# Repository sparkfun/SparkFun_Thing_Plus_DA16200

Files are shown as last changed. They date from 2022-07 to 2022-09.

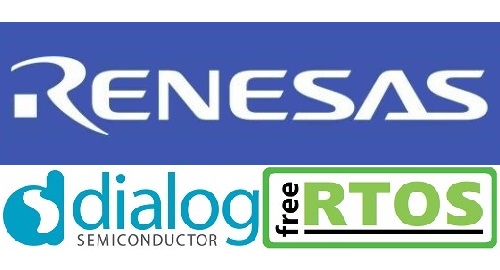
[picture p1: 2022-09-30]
docs/img/sdk_guide/thumbnail/thumbnail.jpg

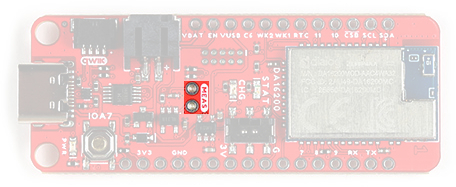
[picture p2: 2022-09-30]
docs/img/hookup_guide/DA16200_thing_plus-MEAS.jpg

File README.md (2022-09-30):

SparkFun Thing Plus - DA16200
========================================

SparkFun Thing Plus - DA16200 (https://www.sparkfun.com/products/19696)

[*SparkFun Thing Plus - DA16200 (WRL-19696)*](https://www.sparkfun.com/products/19696)

The DA16200MOD is an ultra low power WiFi module manufactured by [Dialog (a subsidiary of Renesas)](https://www.renesas.com/us/en). It contains a 802.11b/g/n radio (PHY), a baseband processor, a media access controller (MAC), on-chip memory, and a host networking application processor, all on a single silicon die. The system on a chip (SoC) has full offload capabilities to run the entire networking OS and TCP/IP stack on chip; therefore, an external network processor, CPU, or microcontroller are not required.

The module is Wi-Fi Alliance certified for IEEE802.11b/g/n, Wi-Fi Direct, WPS functionalities and it has been approved by many countries including the United States (FCC), Canada (IC) and China (SRRC). Using the Wi-Fi Alliance transfer policy, the Wi-Fi Certifications can be transferred without being tested again. 

This module is now available in a [Thing Plus form factor](https://www.sparkfun.com/thing_plus), which includes a Qwiic and LiPo battery connectors, multiple GPIO pins, and JTAG PTH pins for debugging. The SparkFun Thing Plus - DA16200 is ideal for your next IoT project, thanks in part to the multiple sleep modes that allow you to take advantage of current draws as low as 0.2 - 3.5 &micro;A on the WiFi module.

***Note:** Please be aware that the Thing Plus - DA16200 has a **3.3V** logic level voltage.*

_The SparkFun [Qwiic connect system](https://www.sparkfun.com/qwiic) is an ecosystem of I2C sensors, actuators, shields and cables that make prototyping faster and less prone to error. All Qwiic-enabled boards use a common 1mm pitch, 4-pin JST connector. This reduces the amount of required PCB space, and polarized connections mean you can't hook it up wrong._

Repository Contents
-------------------

* **[/docs](/docs/)** - Documentation files
    * [board_files](/docs/board_files/) - Files for the product design
        * [Eagle design files](/docs/board_files/eagle_files.zip) (.zip)
        * [Schematic](/docs/board_files/schematic.pdf) (.pdf)
        * [Dimensions](/docs/board_files/dimensions.pdf) (.pdf)
    * [component_documentation](/docs/component_datasheets/) - Datasheets and guides for hardware components
    * [img/hookup_guide/](/docs/img/hookup_guide/) - Images for hookup guide documentation
* **[/Firmware](/Firmware/)** - Prebuilt Example Projects
* **/Hardware** - Eagle design files (.brd, .sch)
* **/Hardware/Production** - Production panel files (.brd)
* **Logic Analyzer Data** - Logic analyzer data from testing

Documentation
--------------

* [DA16200MOD Datasheet](https://www.renesas.com/document/dst/da16200mod-datasheet?language=en&r=1599971) (v3.1)
* [Hookup Guide](https://learn.sparkfun.com/tutorials/2517)
* [Getting Started with the DA16200 FreeRTOS SDK Tutorial](https://learn.sparkfun.com/tutorials/2418)
* [Dialog DA16200MOD Product Page](https://www.renesas.com/us/en/products/interface-connectivity/wireless-communications/wi-fi/da16200mod-ultra-low-power-wi-fi-modules-battery-powered-iot-devices)
  * [Documentation for the DA16200](https://www.renesas.com/us/en/products/interface-connectivity/wireless-communications/wi-fi/da16200mod-ultra-low-power-wi-fi-modules-battery-powered-iot-devices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)       
  * [Software and Tools for the DA16200](https://www.renesas.com/us/en/products/interface-connectivity/wireless-communications/wi-fi/da16200mod-ultra-low-power-wi-fi-modules-battery-powered-iot-devices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)
  * [Support for the DA16200](https://www.renesas.com/us/en/products/interface-connectivity/wireless-communications/wi-fi/da16200mod-ultra-low-power-wi-fi-modules-battery-powered-iot-devices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)
    * [RenesasRulz Forum](https://renesasrulz.com/)

Product Versions
----------------
* [WRL-19696](https://www.sparkfun.com/products/19696) -  initial release

License Information
-------------------

This product is _**open source**_! 

Please review the LICENSE.md file for license information. 

If you have any questions or concerns on licensing, please contact technical support on our [SparkFun forums](https://forum.sparkfun.com/index.php).

Distributed as-is; no warranty is given.

- Your friends at SparkFun.

_<COLLABORATION CREDIT>_

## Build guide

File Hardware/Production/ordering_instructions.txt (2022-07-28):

panel size, 107x204mm
PCB thickness, 1.6mm
number of layers, 4
soldermask color, Red
silkscreen color, White
oz copper, 1oz
finish, HASL lead free
stencils, top
pcs per panel, 12
min trace width, 0.1778mm / 0.0070in
min drill size, 0.3048mm / 0.0120in
filename to layer stackup 1/2/3/4: GTL, GL2, GL3, GBL

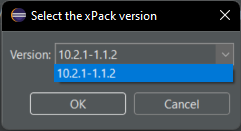
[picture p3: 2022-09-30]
docs/img/sdk_guide/eclipse-preferences-arm_toolchain-xpack_version.png

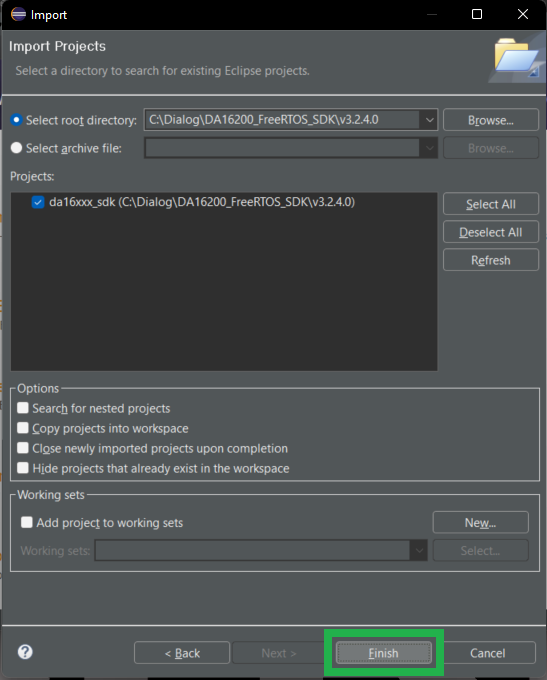
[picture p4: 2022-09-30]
docs/img/sdk_guide/eclipse-import_projects-finish.png

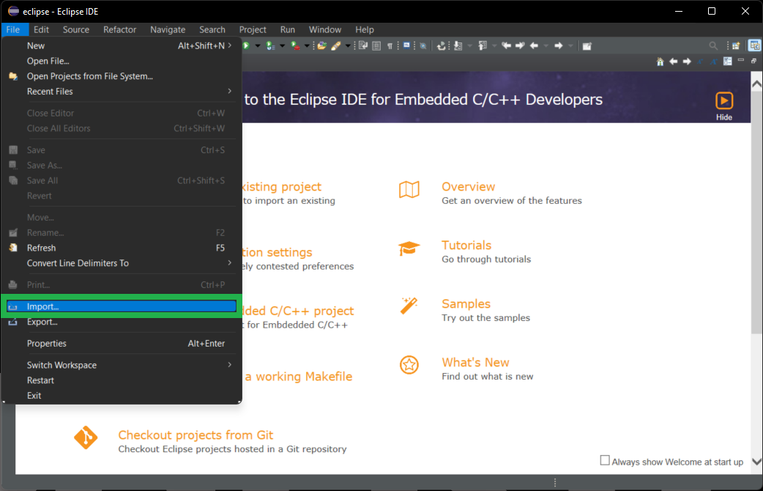
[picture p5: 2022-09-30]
docs/img/sdk_guide/eclipse-file_menu-import.png

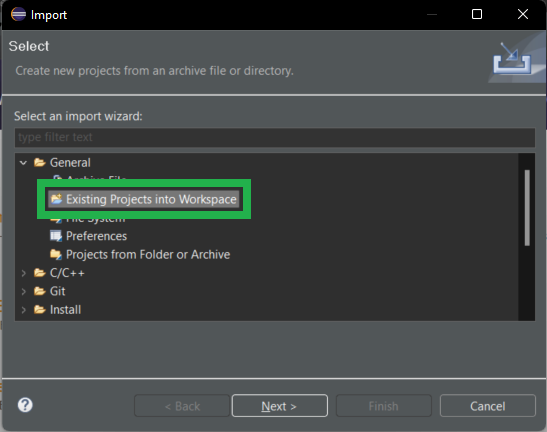
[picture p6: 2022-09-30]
docs/img/sdk_guide/eclipse-import_select.png

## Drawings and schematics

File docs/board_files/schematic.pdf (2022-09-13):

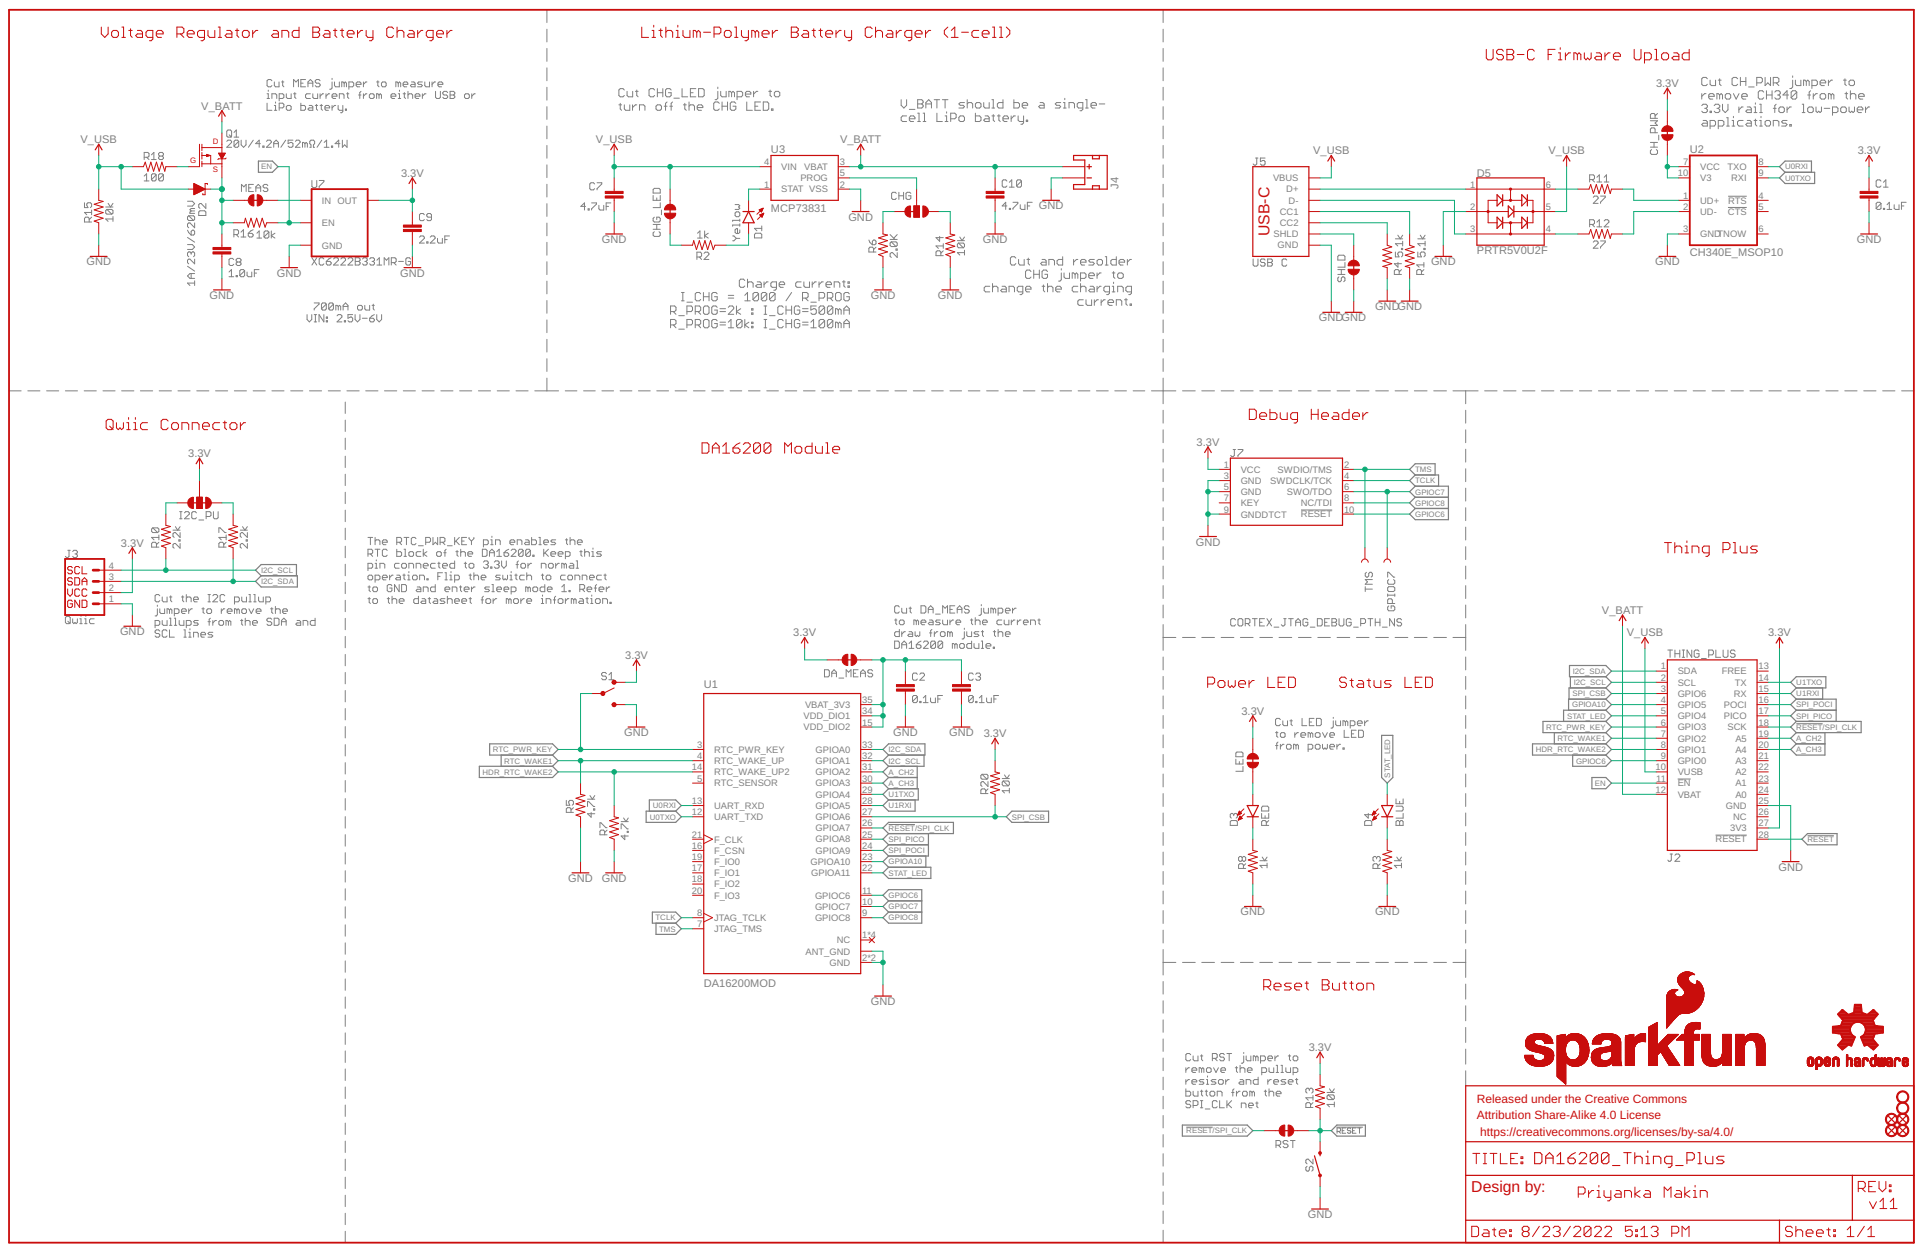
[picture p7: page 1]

Released under the Creative Commons Attribution Share-Alike 4.0 License

https://creativecommons.org/licenses/by-sa/4.0/ Design by:

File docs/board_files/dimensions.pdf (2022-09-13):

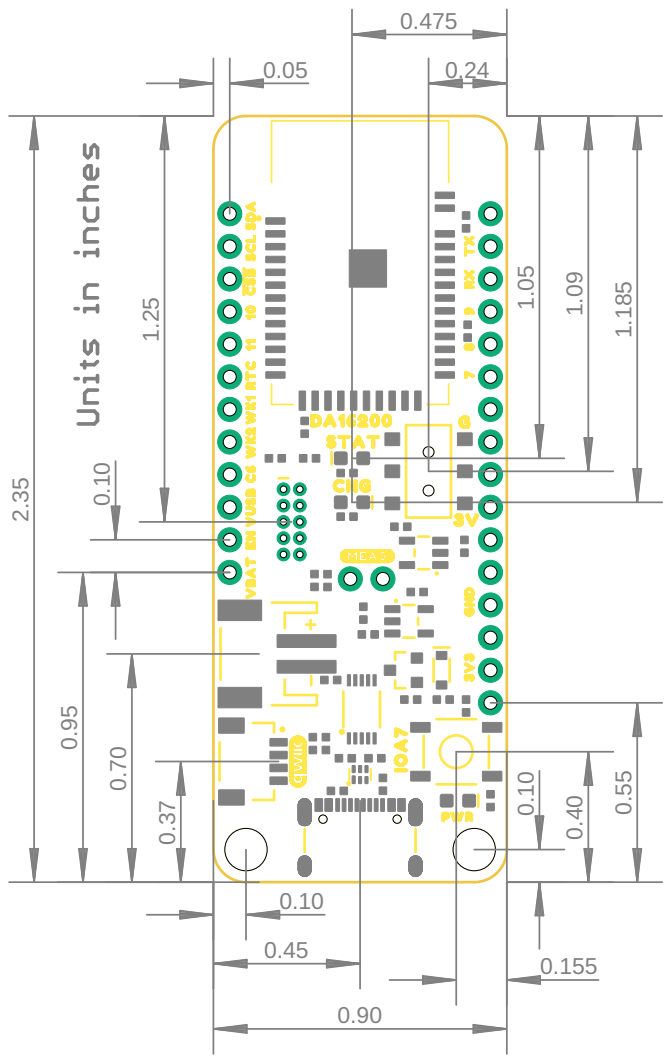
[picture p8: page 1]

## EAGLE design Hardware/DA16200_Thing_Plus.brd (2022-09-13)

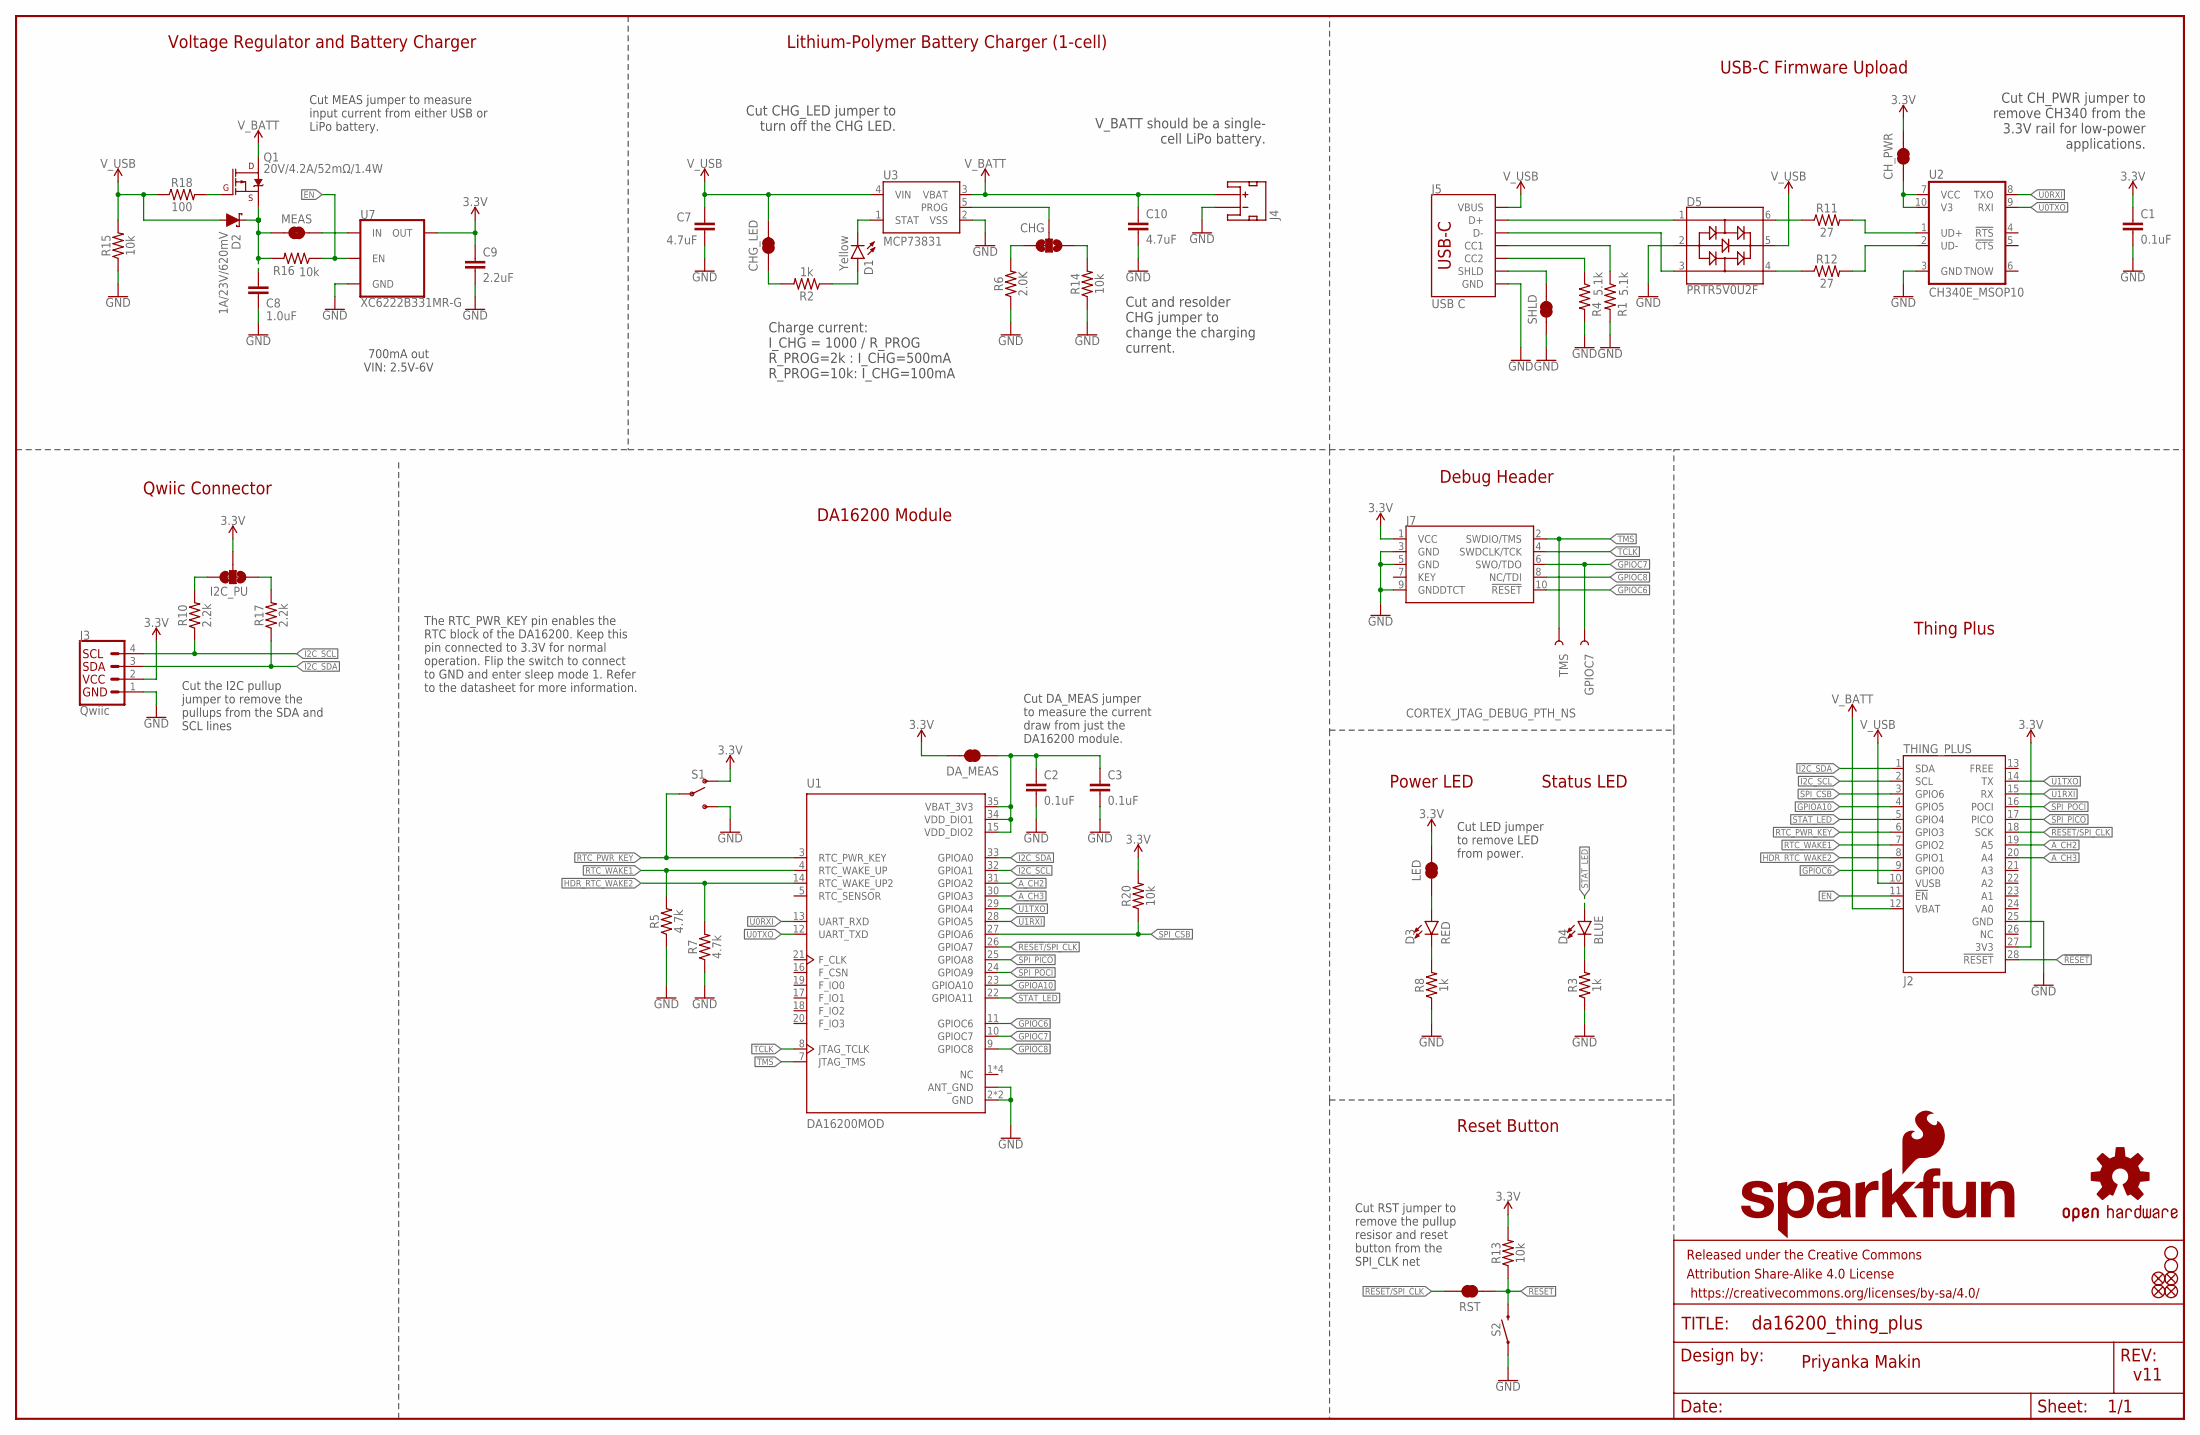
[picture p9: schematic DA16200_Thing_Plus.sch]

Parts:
C1, C2, C3: 0.1uF; 0402-TIGHT
C7, C10: 4.7uF; 0402-TIGHT
C8: 1.0uF; 0402-TIGHT
C9: 2.2uF; 0402-TIGHT
CHG: JUMPER-SMT_3_1-NC_TRACE_SILK; SMT-JUMPER_3_1-NC_TRACE_SILK
CHG_LED: JUMPER-SMT_2_NC_TRACE_SILK; SMT-JUMPER_2_NC_TRACE_SILK
CH_PWR: JUMPER-SMT_2_NC_TRACE_SILK; SMT-JUMPER_2_NC_TRACE_SILK
D1: Yellow; LED-0603
D2: 1A/23V/620mV; SOD-323
D3: RED; LED-0603
D4: BLUE; LED-0603
D5: PRTR5V0U2F; SOT886
DA_MEAS: JUMPER-SMT_2_NC_TRACE_SILK; SMT-JUMPER_2_NC_TRACE_SILK
FD1, FD2, FD3, FD4: FIDUCIALUFIDUCIAL; FIDUCIAL-MICRO
FRAME1: FRAME-LEDGER; CREATIVE_COMMONS
GPIOC7: TEST-POINT3; PAD.03X.03
H3, H4: STAND-OFF
I2C_PU: JUMPER-SMT_3_2-NC_TRACE_SILK; SMT-JUMPER_3_2-NC_TRACE_SILK
J2: THING_PLUS
J3: Qwiic; JST04_1MM_RA
J4: JST_2MM_MALE; JST-2-SMD
J5: USB C; USB-C-16P-4LAYER-ISOLATED
J7: CORTEX_JTAG_DEBUG_PTH_NS; 2X5-PTH-1.27MM-NO_SILK
LED: JUMPER-SMT_2_NC_TRACE_SILK; SMT-JUMPER_2_NC_TRACE_SILK
LOGO1: OSHW-LOGOS; OSHW-LOGO-S
LOGO2: SFE_LOGO_NAME_FLAME.1_INCH; SFE_LOGO_NAME_FLAME_.1
MEAS: JUMPER-COMBO_2_NC_TRACE; COMBO-JUMPER_2_NC_TRACE
Q1: 20V/4.2A/52mΩ/1.4W; SOT23-3
R1, R4: 5.1k; 0402-TIGHT
R2, R3, R8: 1k; 0402-TIGHT
R5, R7: 4.7k; 0402-TIGHT
R6: 2.0K; 0402-TIGHT
R10, R17: 2.2k; 0402-TIGHT
R11, R12: 27; 0402-TIGHT
R13, R14, R15, R16, R20: 10k; 0402-TIGHT
R18: 100; 0402-TIGHT
RST: JUMPER-SMT_2_NC_TRACE_SILK; SMT-JUMPER_2_NC_TRACE_SILK
S1: SWITCH-SPDT-SMD-AYZ0202; SWITCH_DPDT_SMD_AYZ0202
S2: MOMENTARY-SWITCH-SPST-SMD-5.2MM-TALL; TACTILE_SWITCH_SMD_5.2MM
SHLD: JUMPER-SMT_2_NC_TRACE_SILK; SMT-JUMPER_2_NC_TRACE_SILK
TMS: TEST-POINT3; PAD.03X.03
U1: DA16200MOD; XCVR_DA16200MOD-AAC4WA32
U2: CH340E_MSOP10; MSOP10
U3: MCP73831; SOT23-5
U7: XC6222B331MR-G; SOT23-5

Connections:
3.3V: C1.1, C9.1, CH_PWR.2, DA_MEAS.2, I2C_PU.2, J2.27 (3V3), J3.2, J7.1 (VCC), LED.2, R13.2, R20.2, S1.1 (O), U7.5 (OUT)
!RESET!: J2.28 (!RESET), R13.1, RST.1, S2.3 (2)
!RESET!/SPI_CLK: J2.18 (SCK), RST.2, U1.26 (GPIOA7)
A_CH2: J2.19 (A5), U1.31 (GPIOA2)
A_CH3: J2.20 (A4), U1.30 (GPIOA3)
EN: J2.11 (!EN), R16.1, U7.3 (EN)
GND: C1.2, C2.2, C3.2, C7.2, C8.2, C9.2, C10.2, D5.2, J2.25 (GND), J3.1, J4.1 (-), J5.GND, J5.GND2 (GND), J7.3 (GND), J7.5 (GND), J7.9 (GNDDTCT), R1.2, R3.1, R4.2, R5.1, R6.1, R7.1, R8.1, R14.1, R15.1, S1.3 (S), S2.1, SHLD.1, U1.2 (GND), U1.ANT_GND, U1.GND, U2.3 (GND), U3.2 (VSS), U7.2 (GND)
GPIOA10: J2.4 (GPIO5), U1.23 (GPIOA10)
GPIOC6: J2.9 (GPIO0), J7.10 (!RESET), U1.11 (GPIOC6)
GPIOC7: GPIOC7.1, J7.6 (SWO/TDO), U1.10 (GPIOC7)
GPIOC8: J7.8 (NC/TDI), U1.9 (GPIOC8)
HDR_RTC_WAKE2: J2.8 (GPIO1), R7.2, U1.14 (RTC_WAKE_UP2)
I2C_SCL: J2.2 (SCL), J3.4, R10.1, U1.32 (GPIOA1)
I2C_SDA: J2.1 (SDA), J3.3, R17.1, U1.33 (GPIOA0)
unnamed: D4.C, R3.2
unnamed: I2C_PU.3, R10.2
unnamed: I2C_PU.1, R17.2
unnamed: D3.A, LED.1
unnamed: D5.1, J5.A6 (D+), J5.B6 (D+)
unnamed: D5.3, J5.A7 (D-), J5.B7 (D-)
unnamed: D3.C, R8.2
unnamed: C2.1, C3.1, DA_MEAS.1, U1.15 (VDD_DIO2), U1.34 (VDD_DIO1), U1.35 (VBAT_3V3)
unnamed: D1.C, U3.1 (STAT)
unnamed: CHG.3, R6.2
unnamed: J5.A5 (CC1), R1.1
unnamed: J5.B5 (CC2), R4.1
unnamed: D5.6, R11.1
unnamed: CHG.2, U3.5 (PROG)
unnamed: C8.1, D2.C, MEAS.1, MEAS.3 (1), Q1.2 (S), R16.2
unnamed: D5.4, R12.1
unnamed: D1.A, R2.1
unnamed: R11.2, U2.1 (UD+)
unnamed: R12.2, U2.2 (UD-)
unnamed: CHG.1, R14.2
unnamed: Q1.1 (G), R18.2
unnamed: MEAS.2, MEAS.4 (2), U7.1 (IN)
unnamed: CHG_LED.1, R2.2
unnamed: J5.SHLD1 (SHLD), J5.SHLD2 (SHLD), J5.SHLD3 (SHLD), J5.SHLD4 (SHLD), J5.SHLD5 (SHLD), J5.SHLD6 (SHLD), J5.SHLD7 (SHLD), J5.SHLD8 (SHLD), SHLD.2
unnamed: CH_PWR.1, U2.7 (VCC), U2.10 (V3)
RTC_PWR_KEY: J2.6 (GPIO3), S1.2, U1.3 (RTC_PWR_KEY)
RTC_WAKE1: J2.7 (GPIO2), R5.2, U1.4 (RTC_WAKE_UP)
SPI_CSB: J2.3 (GPIO6), R20.1, U1.27 (GPIOA6)
SPI_PICO: J2.17 (PICO), U1.25 (GPIOA8)
SPI_POCI: J2.16 (POCI), U1.24 (GPIOA9)
STAT_LED: D4.A, J2.5 (GPIO4), U1.22 (GPIOA11)
TCLK: J7.4 (SWDCLK/TCK), U1.8 (JTAG_TCLK)
TMS: J7.2 (SWDIO/TMS), TMS.1, U1.7 (JTAG_TMS)
U0RXI: U1.13 (UART_RXD), U2.8 (TXO)
U0TXO: U1.12 (UART_TXD), U2.9 (RXI)
U1RXI: J2.15 (RX), U1.28 (GPIOA5)
U1TXO: J2.14 (TX), U1.29 (GPIOA4)
V_BATT: C10.1, J2.12 (VBAT), J4.2 (+), Q1.3 (D), U3.3 (VBAT)
V_USB: C7.1, CHG_LED.2, D2.A, D5.5, J2.10 (VUSB), J5.VBUS1 (VBUS), J5.VBUS2 (VBUS), R15.2, R18.1, U3.4 (VIN)

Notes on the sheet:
V_BATT should be a single- cell LiPo battery.
Charge current: I_CHG = 1000 / R_PROG R_PROG=2k : I_CHG=500mA R_PROG=10k: I_CHG=100mA
Voltage Regulator and Battery Charger
Lithium-Polymer Battery Charger (1-cell)
700mA out VIN: 2.5V-6V
Reset Button
Status LED
Thing Plus
v11
Qwiic Connector
USB-C Firmware Upload
Cut the I2C pullup jumper to remove the pullups from the SDA and SCL lines
Debug Header
Power LED
Priyanka Makin
DA16200 Module
Cut MEAS jumper to measure input current from either USB or LiPo battery.
Cut and resolder CHG jumper to change the charging current.
Cut LED jumper to remove LED from power.
The RTC_PWR_KEY pin enables the RTC block of the DA16200. Keep this pin connected to 3.3V for normal operation. Flip the switch to connect to GND and enter sleep mode 1. Refer to the datasheet for more information.
Cut DA_MEAS jumper to measure the current draw from just the DA16200 module.
Cut CHG_LED jumper to turn off the CHG LED.
Cut CH_PWR jumper to remove CH340 from the 3.3V rail for low-power applications.
Cut RST jumper to remove the pullup resisor and reset button from the SPI_CLK net

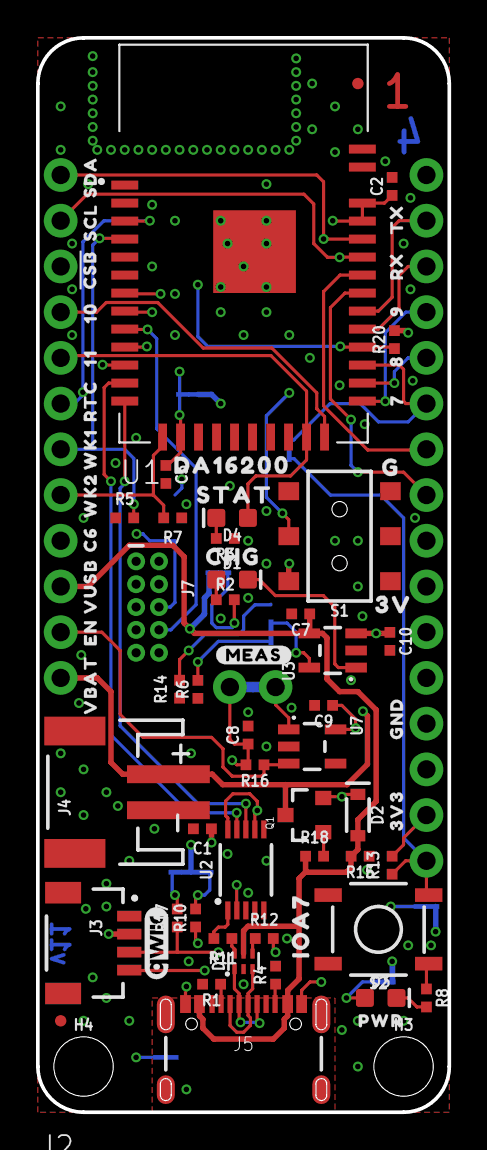
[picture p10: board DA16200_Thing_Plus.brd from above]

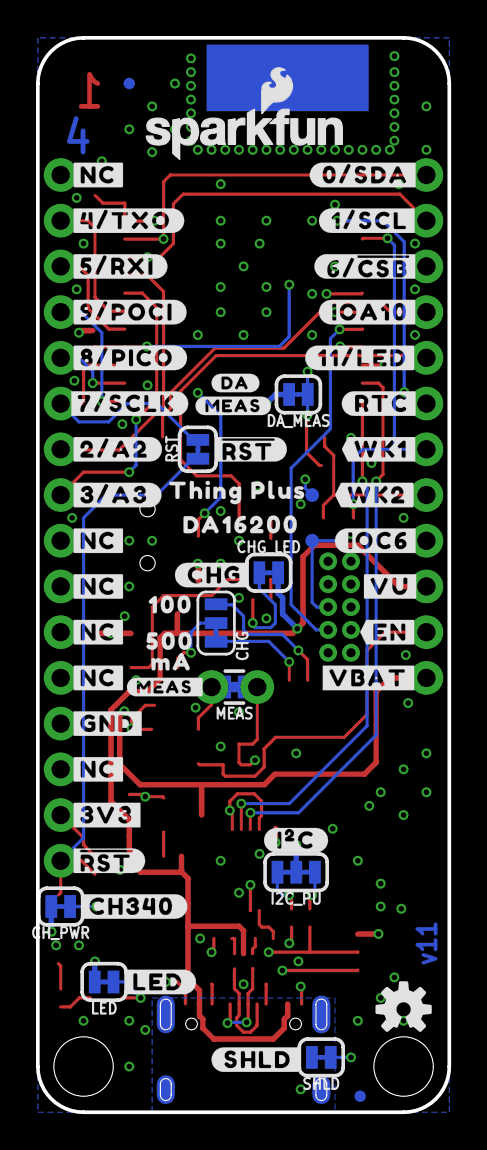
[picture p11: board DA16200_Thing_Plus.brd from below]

Board: 4 copper layers, 22.9 x 59.7 mm, 133 parts (57 on the bottom side), 53 nets.

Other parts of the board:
U$1: STAT0
U$2: CHG0
U$3: #MEAS_#0
U$4: G0
U$5, U$43: ##RST##0
U$6: #VU#0
U$7: #IOA10#0
U$8, U$29: #MEAS#0
U$9: 3V0
U$10: #CH340#0
U$11: #0#SDA#0
U$12: #1#SCL#0
U$13: IOA7_0
U$14, U$15, U$18, U$19, U$20, U$40: #NC#0
U$16: PWR0
U$17: #DA#0
U$21: 5000
U$22: 1000
U$23: MA0
U$24: SDA0
U$25: SCL0
U$26: #CSB#0
U$27: #4#TXO#0
U$28: 110
U$30: #VBAT#0
U$31: ORDERING_INSTRUCTIONS
U$32: 100
U$33: RTC0
U$34: WK10
U$35: WK20
U$36: #5#RXI#0
U$37: EN0
U$38: VUSB0
U$39: VBAT0
U$41: TX0
U$42: RX0
U$44: 90
U$45: 80
U$47: 70
U$50: #GND#0
U$51: #3V3#0
U$53: #EN#0
U$55: GND0
U$56: THING_PLUS0
U$57: 3V30
U$59: #CHG#0
U$60: #IOC6#0
U$62: #6##CSB##0
U$63: #11#LED#0
U$64: QWIIC_4MM
U$65: C60
U$66: #9#POCI#0
U$67: #8#PICO#0
U$68: #7#SCLK#0
U$69: #2#A2#0
U$70: #3#A3#0
U$71: #WK2#0
U$72: #WK1#0
U$73: #RTC#0
U$80, U$81: DA162000
U$82: #I�C#0
U$84: #LED#0
U$85: #SHLD#0

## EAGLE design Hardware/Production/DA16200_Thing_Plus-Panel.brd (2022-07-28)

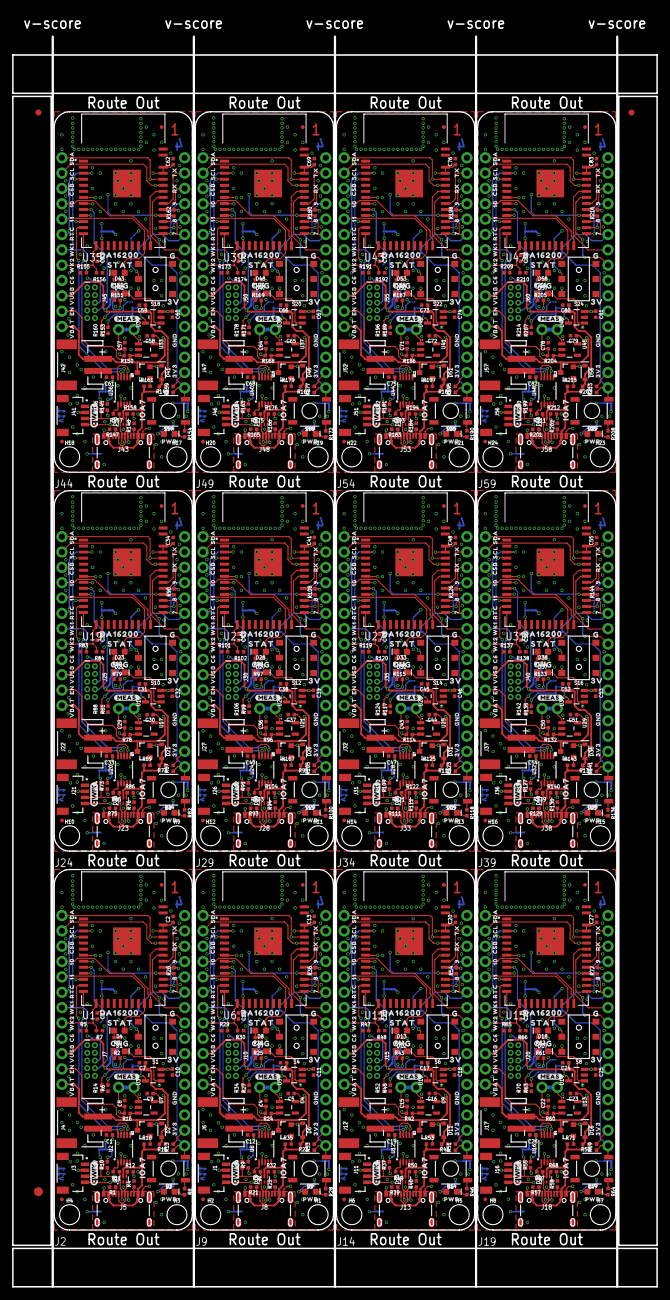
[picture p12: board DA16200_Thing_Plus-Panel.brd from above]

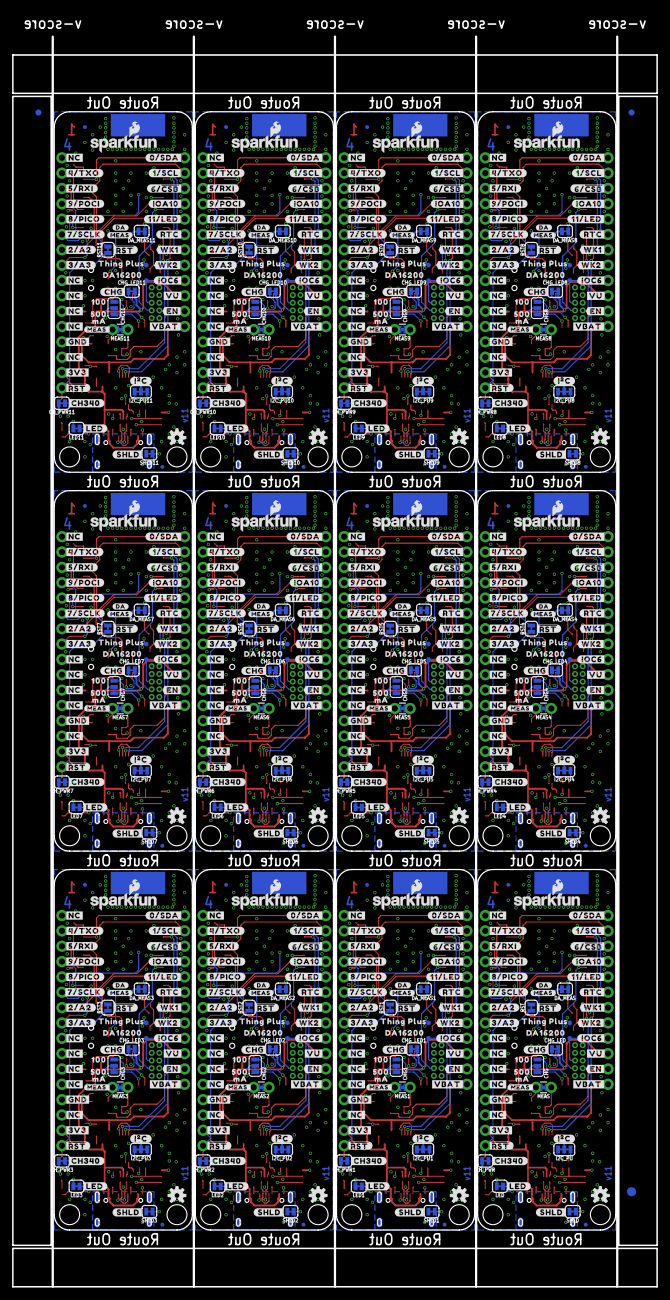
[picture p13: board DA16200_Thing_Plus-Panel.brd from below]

Board: 4 copper layers, 106.7 x 207.0 mm, 1578 parts (687 on the bottom side), 636 nets.

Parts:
C1, C2, C3, C12, C13, C14, C19, C20, C21, C26, C27, C28, C33, C34, C35, C40, C41, C42, C47, C48, C49, C54, C55, C56, C61, C62, C63, C68, C69, C70, C75, C76, C77, C82, C83, C84: 0.1uF; 0402-TIGHT
C4, C8, C15, C22, C29, C36, C43, C50, C57, C64, C71, C78: 1.0uF; 0402-TIGHT
C5, C9, C16, C23, C30, C37, C44, C51, C58, C65, C72, C79: 2.2uF; 0402-TIGHT
C6, C7, C10, C11, C17, C18, C24, C25, C31, C32, C38, C39, C45, C46, C52, C53, C59, C60, C66, C67, C73, C74, C80, C81: 4.7uF; 0402-TIGHT
CHG, CHG1, CHG2, CHG3, CHG4, CHG5, CHG6, CHG7, CHG8, CHG9, CHG10, CHG11: JUMPER-SMT_3_1-NC_TRACE_SILK; SMT-JUMPER_3_1-NC_TRACE_SILK
CHG_LED, CHG_LED1, CHG_LED2, CHG_LED3, CHG_LED4, CHG_LED5, CHG_LED6, CHG_LED7, CHG_LED8, CHG_LED9, CHG_LED10, CHG_LED11: JUMPER-SMT_2_NC_TRACE_SILK; SMT-JUMPER_2_NC_TRACE_SILK
CH_PWR, CH_PWR1, CH_PWR2, CH_PWR3, CH_PWR4, CH_PWR5, CH_PWR6, CH_PWR7, CH_PWR8, CH_PWR9, CH_PWR10, CH_PWR11: JUMPER-SMT_2_NC_TRACE_SILK; SMT-JUMPER_2_NC_TRACE_SILK
D1, D7, D12, D17, D22, D27, D32, D37, D42, D47, D52, D57: Yellow; LED-0603
D2, D6, D11, D16, D21, D26, D31, D36, D41, D46, D51, D56: 1A/23V/620mV; SOD-323
D3, D9, D14, D19, D24, D29, D34, D39, D44, D49, D54, D59: RED; LED-0603
D4, D8, D13, D18, D23, D28, D33, D38, D43, D48, D53, D58: BLUE; LED-0603
D5, D10, D15, D20, D25, D30, D35, D40, D45, D50, D55, D60: PRTR5V0U2F; SOT886
DA_MEAS, DA_MEAS1, DA_MEAS2, DA_MEAS3, DA_MEAS4, DA_MEAS5, DA_MEAS6, DA_MEAS7, DA_MEAS8, DA_MEAS9, DA_MEAS10, DA_MEAS11: JUMPER-SMT_2_NC_TRACE_SILK; SMT-JUMPER_2_NC_TRACE_SILK
E$1, E$2, E$3, E$4: FIDUCIAL-1X2
E$5, E$6: FIDUCIAL-1.5X3
FD1, FD2, FD3, FD4, FD5, FD6, FD7, FD8, FD9, FD10, FD11, FD12, FD13, FD14, FD15, FD16, FD17, FD18, FD19, FD20, FD21, FD22, FD23, FD24, FD25, FD26, FD27, FD28, FD29, FD30, FD31, FD32, FD33, FD34, FD35, FD36, FD37, FD38, FD39, FD40, FD41, FD42, FD43, FD44, FD45, FD46, FD47, FD48: FIDUCIALUFIDUCIAL; FIDUCIAL-MICRO
GPIOC1, GPIOC2, GPIOC3, GPIOC4, GPIOC5, GPIOC6, GPIOC7, GPIOC8, GPIOC9, GPIOC10, GPIOC11, GPIOC12: TEST-POINT3; PAD.03X.03
H1, H2, H3, H4, H5, H6, H7, H8, H9, H10, H11, H12, H13, H14, H15, H16, H17, H18, H19, H20, H21, H22, H23, H24: STAND-OFF
I2C_PU, I2C_PU1, I2C_PU2, I2C_PU3, I2C_PU4, I2C_PU5, I2C_PU6, I2C_PU7, I2C_PU8, I2C_PU9, I2C_PU10, I2C_PU11: JUMPER-SMT_3_2-NC_TRACE_SILK; SMT-JUMPER_3_2-NC_TRACE_SILK
J1, J3, J11, J16, J21, J26, J31, J36, J41, J46, J51, J56: Qwiic; JST04_1MM_RA
J2, J9, J14, J19, J24, J29, J34, J39, J44, J49, J54, J59: THING_PLUS
J4, J6, J12, J17, J22, J27, J32, J37, J42, J47, J52, J57: JST-2-SMD
J5, J8, J13, J18, J23, J28, J33, J38, J43, J48, J53, J58: USB C; USB-C-16P-4LAYER-ISOLATED
J7, J10, J15, J20, J25, J30, J35, J40, J45, J50, J55, J60: CORTEX_JTAG_DEBUG_PTH_NS; 2X5-PTH-1.27MM-NO_SILK
LED, LED1, LED2, LED3, LED4, LED5, LED6, LED7, LED8, LED9, LED10, LED11: JUMPER-SMT_2_NC_TRACE_SILK; SMT-JUMPER_2_NC_TRACE_SILK
LOGO1, LOGO3, LOGO5, LOGO7, LOGO9, LOGO11, LOGO13, LOGO15, LOGO17, LOGO19, LOGO21, LOGO23: OSHW-LOGOS; OSHW-LOGO-S
LOGO2, LOGO4, LOGO6, LOGO8, LOGO10, LOGO12, LOGO14, LOGO16, LOGO18, LOGO20, LOGO22, LOGO24: SFE_LOGO_NAME_FLAME.1_INCH; SFE_LOGO_NAME_FLAME_.1
MEAS, MEAS1, MEAS2, MEAS3, MEAS4, MEAS5, MEAS6, MEAS7, MEAS8, MEAS9, MEAS10, MEAS11: JUMPER-COMBO_2_NC_TRACE; COMBO-JUMPER_2_NC_TRACE
Q1, Q2, Q3, Q4, Q5, Q6, Q7, Q8, Q9, Q10, Q11, Q12: 20V/4.2A/52mΩ/1.4W; SOT23-3
R1, R4, R21, R22, R39, R40, R57, R58, R75, R76, R93, R94, R111, R112, R129, R130, R147, R148, R165, R166, R183, R184, R201, R202: 5.1k; 0402-TIGHT
R2, R3, R8, R25, R26, R28, R43, R44, R46, R61, R62, R64, R79, R80, R82, R97, R98, R100, R115, R116, R118, R133, R134, R136, R151, R152, R154, R169, R170, R172, R187, R188, R190, R205, R206, R208: 1k; 0402-TIGHT
R5, R7, R29, R30, R47, R48, R65, R66, R83, R84, R101, R102, R119, R120, R137, R138, R155, R156, R173, R174, R191, R192, R209, R210: 4.7k; 0402-TIGHT
R6, R27, R45, R63, R81, R99, R117, R135, R153, R171, R189, R207: 2.0K; 0402-TIGHT
R9, R10, R17, R19, R37, R38, R55, R56, R73, R74, R91, R92, R109, R110, R127, R128, R145, R146, R163, R164, R181, R182, R199, R200: 2.2k; 0402-TIGHT
R11, R12, R31, R32, R49, R50, R67, R68, R85, R86, R103, R104, R121, R122, R139, R140, R157, R158, R175, R176, R193, R194, R211, R212: 27; 0402-TIGHT
R13, R14, R15, R16, R20, R23, R24, R33, R34, R36, R41, R42, R51, R52, R54, R59, R60, R69, R70, R72, R77, R78, R87, R88, R90, R95, R96, R105, R106, R108, R113, R114, R123, R124, R126, R131, R132, R141, R142, R144, R149, R150, R159, R160, R162, R167, R168, R177, R178, R180, R185, R186, R195, R196, R198, R203, R204, R213, R214, R216: 10k; 0402-TIGHT
R18, R35, R53, R71, R89, R107, R125, R143, R161, R179, R197, R215: 100; 0402-TIGHT
RST, RST1, RST2, RST3, RST4, RST5, RST6, RST7, RST8, RST9, RST10, RST11: JUMPER-SMT_2_NC_TRACE_SILK; SMT-JUMPER_2_NC_TRACE_SILK
S1, S4, S6, S8, S10, S12, S14, S16, S18, S20, S22, S24: SWITCH_DPDT_SMD_AYZ0202
S2, S3, S5, S7, S9, S11, S13, S15, S17, S19, S21, S23: MOMENTARY-SWITCH-SPST-SMD-5.2MM-TALL; TACTILE_SWITCH_SMD_5.2MM
SHLD, SHLD1, SHLD2, SHLD3, SHLD4, SHLD5, SHLD6, SHLD7, SHLD8, SHLD9, SHLD10, SHLD11: JUMPER-SMT_2_NC_TRACE_SILK; SMT-JUMPER_2_NC_TRACE_SILK
TMS, TMS1, TMS2, TMS3, TMS4, TMS5, TMS6, TMS7, TMS8, TMS9, TMS10, TMS11: TEST-POINT3; PAD.03X.03
U1, U6, U11, U15, U19, U23, U27, U31, U35, U39, U43, U47: DA16200MOD; XCVR_DA16200MOD-AAC4WA32
U2, U8, U12, U16, U20, U24, U28, U32, U36, U40, U44, U48: CH340E_MSOP10; MSOP10
U3, U5, U10, U14, U18, U22, U26, U30, U34, U38, U42, U46: MCP73831; SOT23-5
U4, U7, U9, U13, U17, U21, U25, U29, U33, U37, U41, U45: XC6222B331MR-G; SOT23-5
U$1, U$86, U$156, U$226, U$296, U$366, U$436, U$506, U$576, U$646, U$716, U$786: STAT0
U$2, U$87, U$157, U$227, U$297, U$367, U$437, U$507, U$577, U$647, U$717, U$787: CHG0
U$3, U$90, U$160, U$230, U$300, U$370, U$440, U$510, U$580, U$650, U$720, U$790: #MEAS_#0
U$4, U$91, U$161, U$231, U$301, U$371, U$441, U$511, U$581, U$651, U$721, U$791: G0
U$5, U$43, U$88, U$140, U$158, U$210, U$228, U$280, U$298, U$350, U$368, U$420, U$438, U$490, U$508, U$560, U$578, U$630, U$648, U$700, U$718, U$770, U$788, U$840: ##RST##0
U$6, U$94, U$164, U$234, U$304, U$374, U$444, U$514, U$584, U$654, U$724, U$794: #VU#0
U$7, U$129, U$199, U$269, U$339, U$409, U$479, U$549, U$619, U$689, U$759, U$829: #IOA10#0
U$8, U$29, U$89, U$138, U$159, U$208, U$229, U$278, U$299, U$348, U$369, U$418, U$439, U$488, U$509, U$558, U$579, U$628, U$649, U$698, U$719, U$768, U$789, U$838: #MEAS#0
U$9, U$92, U$162, U$232, U$302, U$372, U$442, U$512, U$582, U$652, U$722, U$792: 3V0
U$10, U$123, U$193, U$263, U$333, U$403, U$473, U$543, U$613, U$683, U$753, U$823: #CH340#0
U$11, U$124, U$194, U$264, U$334, U$404, U$474, U$544, U$614, U$684, U$754, U$824: #0#SDA#0
U$12, U$125, U$195, U$265, U$335, U$405, U$475, U$545, U$615, U$685, U$755, U$825: #1#SCL#0
U$13, U$93, U$163, U$233, U$303, U$373, U$443, U$513, U$583, U$653, U$723, U$793: IOA7_0
U$14, U$15, U$18, U$19, U$20, U$40, U$95, U$96, U$97, U$98, U$99, U$114, U$165, U$166, U$167, U$168, U$169, U$184, U$235, U$236, U$237, U$238, U$239, U$254, U$305, U$306, U$307, U$308, U$309, U$324, U$375, U$376, U$377, U$378, U$379, U$394, U$445, U$446, U$447, U$448, U$449, U$464, U$515, U$516, U$517, U$518, U$519, U$534, U$585, U$586, U$587, U$588, U$589, U$604, U$655, U$656, U$657, U$658, U$659, U$674, U$725, U$726, U$727, U$728, U$729, U$744, U$795, U$796, U$797, U$798, U$799, U$814: #NC#0
U$16, U$46, U$142, U$212, U$282, U$352, U$422, U$492, U$562, U$632, U$702, U$772: PWR0
U$17, U$137, U$207, U$277, U$347, U$417, U$487, U$557, U$627, U$697, U$767, U$837: #DA#0
U$21, U$100, U$170, U$240, U$310, U$380, U$450, U$520, U$590, U$660, U$730, U$800: 5000
U$22, U$101, U$171, U$241, U$311, U$381, U$451, U$521, U$591, U$661, U$731, U$801: 1000
U$23, U$102, U$172, U$242, U$312, U$382, U$452, U$522, U$592, U$662, U$732, U$802: MA0
U$24, U$103, U$173, U$243, U$313, U$383, U$453, U$523, U$593, U$663, U$733, U$803: SDA0
U$25, U$104, U$174, U$244, U$314, U$384, U$454, U$524, U$594, U$664, U$734, U$804: SCL0
U$26, U$105, U$175, U$245, U$315, U$385, U$455, U$525, U$595, U$665, U$735, U$805: #CSB#0
U$27, U$130, U$200, U$270, U$340, U$410, U$480, U$550, U$620, U$690, U$760, U$830: #4#TXO#0
U$28, U$113, U$183, U$253, U$323, U$393, U$463, U$533, U$603, U$673, U$743, U$813: 110
U$30, U$139, U$209, U$279, U$349, U$419, U$489, U$559, U$629, U$699, U$769, U$839: #VBAT#0
U$31, U$64, U$141, U$211, U$281, U$351, U$421, U$491, U$561, U$631, U$701, U$771: QWIIC_4MM
U$32, U$106, U$176, U$246, U$316, U$386, U$456, U$526, U$596, U$666, U$736, U$806: 100
U$33, U$107, U$177, U$247, U$317, U$387, U$457, U$527, U$597, U$667, U$737, U$807: RTC0
U$34, U$108, U$178, U$248, U$318, U$388, U$458, U$528, U$598, U$668, U$738, U$808: WK10
U$35, U$109, U$179, U$249, U$319, U$389, U$459, U$529, U$599, U$669, U$739, U$809: WK20
U$36, U$131, U$201, U$271, U$341, U$411, U$481, U$551, U$621, U$691, U$761, U$831: #5#RXI#0
U$37, U$110, U$180, U$250, U$320, U$390, U$460, U$530, U$600, U$670, U$740, U$810: EN0
U$38, U$111, U$181, U$251, U$321, U$391, U$461, U$531, U$601, U$671, U$741, U$811: VUSB0
U$39, U$112, U$182, U$252, U$322, U$392, U$462, U$532, U$602, U$672, U$742, U$812: VBAT0
U$41, U$115, U$185, U$255, U$325, U$395, U$465, U$535, U$605, U$675, U$745, U$815: TX0
U$42, U$116, U$186, U$256, U$326, U$396, U$466, U$536, U$606, U$676, U$746, U$816: RX0
U$44, U$117, U$187, U$257, U$327, U$397, U$467, U$537, U$607, U$677, U$747, U$817: 90
U$45, U$118, U$188, U$258, U$328, U$398, U$468, U$538, U$608, U$678, U$748, U$818: 80
U$47, U$119, U$189, U$259, U$329, U$399, U$469, U$539, U$609, U$679, U$749, U$819: 70
U$48, U$50, U$143, U$213, U$283, U$353, U$423, U$493, U$563, U$633, U$703, U$773: #GND#0
U$49, U$51, U$144, U$214, U$284, U$354, U$424, U$494, U$564, U$634, U$704, U$774: #3V3#0
U$52, U$53, U$145, U$215, U$285, U$355, U$425, U$495, U$565, U$635, U$705, U$775: #EN#0
U$54, U$60, U$146, U$216, U$286, U$356, U$426, U$496, U$566, U$636, U$706, U$776: #IOC6#0
U$55, U$120, U$190, U$260, U$330, U$400, U$470, U$540, U$610, U$680, U$750, U$820: GND0
U$56, U$75, U$150, U$220, U$290, U$360, U$430, U$500, U$570, U$640, U$710, U$780: THING_PLUS0
U$57, U$121, U$191, U$261, U$331, U$401, U$471, U$541, U$611, U$681, U$751, U$821: 3V30
U$58, U$71, U$147, U$217, U$287, U$357, U$427, U$497, U$567, U$637, U$707, U$777: #WK2#0
U$59, U$122, U$192, U$262, U$332, U$402, U$472, U$542, U$612, U$682, U$752, U$822: #CHG#0
U$61, U$72, U$148, U$218, U$288, U$358, U$428, U$498, U$568, U$638, U$708, U$778: #WK1#0
U$62, U$126, U$196, U$266, U$336, U$406, U$476, U$546, U$616, U$686, U$756, U$826: #6##CSB##0
U$63, U$127, U$197, U$267, U$337, U$407, U$477, U$547, U$617, U$687, U$757, U$827: #11#LED#0
U$65, U$128, U$198, U$268, U$338, U$408, U$478, U$548, U$618, U$688, U$758, U$828: C60
U$66, U$132, U$202, U$272, U$342, U$412, U$482, U$552, U$622, U$692, U$762, U$832: #9#POCI#0
U$67, U$133, U$203, U$273, U$343, U$413, U$483, U$553, U$623, U$693, U$763, U$833: #8#PICO#0
U$68, U$134, U$204, U$274, U$344, U$414, U$484, U$554, U$624, U$694, U$764, U$834: #7#SCLK#0
U$69, U$135, U$205, U$275, U$345, U$415, U$485, U$555, U$625, U$695, U$765, U$835: #2#A2#0
U$70, U$136, U$206, U$276, U$346, U$416, U$486, U$556, U$626, U$696, U$766, U$836: #3#A3#0
U$73, U$74, U$149, U$219, U$289, U$359, U$429, U$499, U$569, U$639, U$709, U$779: #RTC#0
U$76, U$77, U$80, U$81, U$151, U$152, U$221, U$222, U$291, U$292, U$361, U$362, U$431, U$432, U$501, U$502, U$571, U$572, U$641, U$642, U$711, U$712, U$781, U$782: DA162000
U$78, U$82, U$153, U$223, U$293, U$363, U$433, U$503, U$573, U$643, U$713, U$783: #I�C#0
U$79, U$84, U$154, U$224, U$294, U$364, U$434, U$504, U$574, U$644, U$714, U$784: #LED#0
U$83, U$85, U$155, U$225, U$295, U$365, U$435, U$505, U$575, U$645, U$715, U$785: #SHLD#0

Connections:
3.3V: C1.1, C9.1, CH_PWR.2, DA_MEAS.2, I2C_PU.2, J2.27, J3.2, J7.1, LED.2, R13.2, R20.2, S1.1, U7.5
3.3V1: C5.1, C12.1, CH_PWR1.2, DA_MEAS1.2, I2C_PU1.2, J1.2, J9.27, J10.1, LED1.2, R33.2, R36.2, S4.1, U4.5
3.3V2: C16.1, C19.1, CH_PWR2.2, DA_MEAS2.2, I2C_PU2.2, J11.2, J14.27, J15.1, LED2.2, R51.2, R54.2, S6.1, U9.5
3.3V3: C23.1, C26.1, CH_PWR3.2, DA_MEAS3.2, I2C_PU3.2, J16.2, J19.27, J20.1, LED3.2, R69.2, R72.2, S8.1, U13.5
3.3V4: C30.1, C33.1, CH_PWR4.2, DA_MEAS4.2, I2C_PU4.2, J21.2, J24.27, J25.1, LED4.2, R87.2, R90.2, S10.1, U17.5
3.3V5: C37.1, C40.1, CH_PWR5.2, DA_MEAS5.2, I2C_PU5.2, J26.2, J29.27, J30.1, LED5.2, R105.2, R108.2, S12.1, U21.5
3.3V6: C44.1, C47.1, CH_PWR6.2, DA_MEAS6.2, I2C_PU6.2, J31.2, J34.27, J35.1, LED6.2, R123.2, R126.2, S14.1, U25.5
3.3V7: C51.1, C54.1, CH_PWR7.2, DA_MEAS7.2, I2C_PU7.2, J36.2, J39.27, J40.1, LED7.2, R141.2, R144.2, S16.1, U29.5
3.3V8: C58.1, C61.1, CH_PWR8.2, DA_MEAS8.2, I2C_PU8.2, J41.2, J44.27, J45.1, LED8.2, R159.2, R162.2, S18.1, U33.5
3.3V9: C65.1, C68.1, CH_PWR9.2, DA_MEAS9.2, I2C_PU9.2, J46.2, J49.27, J50.1, LED9.2, R177.2, R180.2, S20.1, U37.5
3.3V10: C72.1, C75.1, CH_PWR10.2, DA_MEAS10.2, I2C_PU10.2, J51.2, J54.27, J55.1, LED10.2, R195.2, R198.2, S22.1, U41.5
3.3V11: C79.1, C82.1, CH_PWR11.2, DA_MEAS11.2, I2C_PU11.2, J56.2, J59.27, J60.1, LED11.2, R213.2, R216.2, S24.1, U45.5
!RESET!: J2.28, R13.1, RST.1, S2.3
!RESET!1: J9.28, R33.1, RST1.1, S3.3
!RESET!2: J14.28, R51.1, RST2.1, S5.3
!RESET!3: J19.28, R69.1, RST3.1, S7.3
!RESET!4: J24.28, R87.1, RST4.1, S9.3
!RESET!5: J29.28, R105.1, RST5.1, S11.3
!RESET!6: J34.28, R123.1, RST6.1, S13.3
!RESET!7: J39.28, R141.1, RST7.1, S15.3
!RESET!8: J44.28, R159.1, RST8.1, S17.3
!RESET!9: J49.28, R177.1, RST9.1, S19.3
!RESET!10: J54.28, R195.1, RST10.1, S21.3
!RESET!11: J59.28, R213.1, RST11.1, S23.3
!RESET!/SPI_CLK: J2.18, RST.2, U1.26
!RESET!/SPI_CLK1: J9.18, RST1.2, U6.26
!RESET!/SPI_CLK2: J14.18, RST2.2, U11.26
!RESET!/SPI_CLK3: J19.18, RST3.2, U15.26
!RESET!/SPI_CLK4: J24.18, RST4.2, U19.26
!RESET!/SPI_CLK5: J29.18, RST5.2, U23.26
!RESET!/SPI_CLK6: J34.18, RST6.2, U27.26
!RESET!/SPI_CLK7: J39.18, RST7.2, U31.26
!RESET!/SPI_CLK8: J44.18, RST8.2, U35.26
!RESET!/SPI_CLK9: J49.18, RST9.2, U39.26
!RESET!/SPI_CLK10: J54.18, RST10.2, U43.26
!RESET!/SPI_CLK11: J59.18, RST11.2, U47.26
A_CH1: J9.19, U6.31
A_CH2: J2.19, U1.31
A_CH3: J2.20, U1.30
A_CH4: J9.20, U6.30
A_CH5: J14.19, U11.31
A_CH6: J14.20, U11.30
A_CH7: J19.19, U15.31
A_CH8: J19.20, U15.30
A_CH9: J24.19, U19.31
A_CH10: J24.20, U19.30
A_CH11: J29.19, U23.31
A_CH12: J29.20, U23.30
A_CH13: J34.19, U27.31
A_CH14: J34.20, U27.30
A_CH15: J39.19, U31.31
A_CH16: J39.20, U31.30
A_CH17: J44.19, U35.31
A_CH18: J44.20, U35.30
A_CH19: J49.19, U39.31
A_CH20: J49.20, U39.30
A_CH21: J54.19, U43.31
A_CH22: J54.20, U43.30
A_CH23: J59.19, U47.31
A_CH24: J59.20, U47.30
EN: J2.11, R16.1, U7.3
EN1: J9.11, R24.1, U4.3
EN2: J14.11, R42.1, U9.3
EN3: J19.11, R60.1, U13.3
EN4: J24.11, R78.1, U17.3
EN5: J29.11, R96.1, U21.3
EN6: J34.11, R114.1, U25.3
EN7: J39.11, R132.1, U29.3
EN8: J44.11, R150.1, U33.3
EN9: J49.11, R168.1, U37.3
EN10: J54.11, R186.1, U41.3
EN11: J59.11, R204.1, U45.3
GND: C1.2, C2.2, C3.2, C7.2, C8.2, C9.2, C10.2, D5.2, J2.25, J3.1, J4.1, J5.GND, J5.GND2, J7.3, J7.5, J7.9, R1.2, R3.1, R4.2, R5.1, R6.1, R7.1, R8.1, R14.1, R15.1, S1.3, S2.1, SHLD.1, U1.2, U1.ANT_GND, U1.GND, U2.3, U3.2, U7.2
GND1: C4.2, C5.2, C6.2, C11.2, C12.2, C13.2, C14.2, D10.2, J1.1, J6.1, J8.GND, J8.GND2, J9.25, J10.3, J10.5, J10.9, R21.2, R22.2, R23.1, R26.1, R27.1, R28.1, R29.1, R30.1, R34.1, S3.1, S4.3, SHLD1.1, U4.2, U5.2, U6.2, U6.ANT_GND, U6.GND, U8.3
GND2: C15.2, C16.2, C17.2, C18.2, C19.2, C20.2, C21.2, D15.2, J11.1, J12.1, J13.GND, J13.GND2, J14.25, J15.3, J15.5, J15.9, R39.2, R40.2, R41.1, R44.1, R45.1, R46.1, R47.1, R48.1, R52.1, S5.1, S6.3, SHLD2.1, U9.2, U10.2, U11.2, U11.ANT_GND, U11.GND, U12.3
GND3: C22.2, C23.2, C24.2, C25.2, C26.2, C27.2, C28.2, D20.2, J16.1, J17.1, J18.GND, J18.GND2, J19.25, J20.3, J20.5, J20.9, R57.2, R58.2, R59.1, R62.1, R63.1, R64.1, R65.1, R66.1, R70.1, S7.1, S8.3, SHLD3.1, U13.2, U14.2, U15.2, U15.ANT_GND, U15.GND, U16.3
GND4: C29.2, C30.2, C31.2, C32.2, C33.2, C34.2, C35.2, D25.2, J21.1, J22.1, J23.GND, J23.GND2, J24.25, J25.3, J25.5, J25.9, R75.2, R76.2, R77.1, R80.1, R81.1, R82.1, R83.1, R84.1, R88.1, S9.1, S10.3, SHLD4.1, U17.2, U18.2, U19.2, U19.ANT_GND, U19.GND, U20.3
GND5: C36.2, C37.2, C38.2, C39.2, C40.2, C41.2, C42.2, D30.2, J26.1, J27.1, J28.GND, J28.GND2, J29.25, J30.3, J30.5, J30.9, R93.2, R94.2, R95.1, R98.1, R99.1, R100.1, R101.1, R102.1, R106.1, S11.1, S12.3, SHLD5.1, U21.2, U22.2, U23.2, U23.ANT_GND, U23.GND, U24.3
GND6: C43.2, C44.2, C45.2, C46.2, C47.2, C48.2, C49.2, D35.2, J31.1, J32.1, J33.GND, J33.GND2, J34.25, J35.3, J35.5, J35.9, R111.2, R112.2, R113.1, R116.1, R117.1, R118.1, R119.1, R120.1, R124.1, S13.1, S14.3, SHLD6.1, U25.2, U26.2, U27.2, U27.ANT_GND, U27.GND, U28.3
GND7: C50.2, C51.2, C52.2, C53.2, C54.2, C55.2, C56.2, D40.2, J36.1, J37.1, J38.GND, J38.GND2, J39.25, J40.3, J40.5, J40.9, R129.2, R130.2, R131.1, R134.1, R135.1, R136.1, R137.1, R138.1, R142.1, S15.1, S16.3, SHLD7.1, U29.2, U30.2, U31.2, U31.ANT_GND, U31.GND, U32.3
GND8: C57.2, C58.2, C59.2, C60.2, C61.2, C62.2, C63.2, D45.2, J41.1, J42.1, J43.GND, J43.GND2, J44.25, J45.3, J45.5, J45.9, R147.2, R148.2, R149.1, R152.1, R153.1, R154.1, R155.1, R156.1, R160.1, S17.1, S18.3, SHLD8.1, U33.2, U34.2, U35.2, U35.ANT_GND, U35.GND, U36.3
GND9: C64.2, C65.2, C66.2, C67.2, C68.2, C69.2, C70.2, D50.2, J46.1, J47.1, J48.GND, J48.GND2, J49.25, J50.3, J50.5, J50.9, R165.2, R166.2, R167.1, R170.1, R171.1, R172.1, R173.1, R174.1, R178.1, S19.1, S20.3, SHLD9.1, U37.2, U38.2, U39.2, U39.ANT_GND, U39.GND, U40.3
GND10: C71.2, C72.2, C73.2, C74.2, C75.2, C76.2, C77.2, D55.2, J51.1, J52.1, J53.GND, J53.GND2, J54.25, J55.3, J55.5, J55.9, R183.2, R184.2, R185.1, R188.1, R189.1, R190.1, R191.1, R192.1, R196.1, S21.1, S22.3, SHLD10.1, U41.2, U42.2, U43.2, U43.ANT_GND, U43.GND, U44.3
GND11: C78.2, C79.2, C80.2, C81.2, C82.2, C83.2, C84.2, D60.2, J56.1, J57.1, J58.GND, J58.GND2, J59.25, J60.3, J60.5, J60.9, R201.2, R202.2, R203.1, R206.1, R207.1, R208.1, R209.1, R210.1, R214.1, S23.1, S24.3, SHLD11.1, U45.2, U46.2, U47.2, U47.ANT_GND, U47.GND, U48.3
GPIOA1: J9.4, U6.23
GPIOA2: J14.4, U11.23
GPIOA3: J19.4, U15.23
GPIOA4: J24.4, U19.23
GPIOA5: J29.4, U23.23
GPIOA6: J34.4, U27.23
GPIOA7: J39.4, U31.23
GPIOA8: J44.4, U35.23
GPIOA9: J49.4, U39.23
GPIOA10: J2.4, U1.23
GPIOA11: J54.4, U43.23
GPIOA12: J59.4, U47.23
GPIOC1: J9.9, J10.10, U6.11
GPIOC2: GPIOC1.1, J10.6, U6.10
GPIOC3: J10.8, U6.9
GPIOC4: J14.9, J15.10, U11.11
GPIOC5: GPIOC2.1, J15.6, U11.10
GPIOC6: J2.9, J7.10, U1.11
GPIOC7: GPIOC7.1, J7.6, U1.10
GPIOC8: J7.8, U1.9
GPIOC9: J15.8, U11.9
GPIOC10: J19.9, J20.10, U15.11
GPIOC11: GPIOC3.1, J20.6, U15.10
GPIOC12: J20.8, U15.9
GPIOC13: J24.9, J25.10, U19.11
GPIOC14: GPIOC4.1, J25.6, U19.10
GPIOC15: J25.8, U19.9
GPIOC16: J29.9, J30.10, U23.11
GPIOC17: GPIOC5.1, J30.6, U23.10
GPIOC18: J30.8, U23.9
GPIOC19: J34.9, J35.10, U27.11
GPIOC20: GPIOC6.1, J35.6, U27.10
GPIOC21: J35.8, U27.9
GPIOC22: J39.9, J40.10, U31.11
GPIOC23: GPIOC8.1, J40.6, U31.10
GPIOC24: J40.8, U31.9
GPIOC25: J44.9, J45.10, U35.11
GPIOC26: GPIOC9.1, J45.6, U35.10
GPIOC27: J45.8, U35.9
GPIOC28: J49.9, J50.10, U39.11
GPIOC29: GPIOC10.1, J50.6, U39.10
GPIOC30: J50.8, U39.9
GPIOC31: J54.9, J55.10, U43.11
GPIOC32: GPIOC11.1, J55.6, U43.10
GPIOC33: J55.8, U43.9
GPIOC34: J59.9, J60.10, U47.11
GPIOC35: GPIOC12.1, J60.6, U47.10
GPIOC36: J60.8, U47.9
HDR_RTC_WAKE1: J9.8, R30.2, U6.14
HDR_RTC_WAKE2: J2.8, R7.2, U1.14
HDR_RTC_WAKE3: J14.8, R48.2, U11.14
HDR_RTC_WAKE4: J19.8, R66.2, U15.14
HDR_RTC_WAKE5: J24.8, R84.2, U19.14
HDR_RTC_WAKE6: J29.8, R102.2, U23.14
HDR_RTC_WAKE7: J34.8, R120.2, U27.14
HDR_RTC_WAKE8: J39.8, R138.2, U31.14
HDR_RTC_WAKE9: J44.8, R156.2, U35.14
HDR_RTC_WAKE10: J49.8, R174.2, U39.14
HDR_RTC_WAKE11: J54.8, R192.2, U43.14
HDR_RTC_WAKE12: J59.8, R210.2, U47.14
I2C_SCL: J2.2, J3.4, R10.1, U1.32
I2C_SCL1: J1.4, J9.2, R9.1, U6.32
I2C_SCL2: J11.4, J14.2, R37.1, U11.32
I2C_SCL3: J16.4, J19.2, R55.1, U15.32
I2C_SCL4: J21.4, J24.2, R73.1, U19.32
I2C_SCL5: J26.4, J29.2, R91.1, U23.32
I2C_SCL6: J31.4, J34.2, R109.1, U27.32
I2C_SCL7: J36.4, J39.2, R127.1, U31.32
I2C_SCL8: J41.4, J44.2, R145.1, U35.32
I2C_SCL9: J46.4, J49.2, R163.1, U39.32
I2C_SCL10: J51.4, J54.2, R181.1, U43.32
I2C_SCL11: J56.4, J59.2, R199.1, U47.32
I2C_SDA: J2.1, J3.3, R17.1, U1.33
I2C_SDA1: J1.3, J9.1, R19.1, U6.33
I2C_SDA2: J11.3, J14.1, R38.1, U11.33
I2C_SDA3: J16.3, J19.1, R56.1, U15.33
I2C_SDA4: J21.3, J24.1, R74.1, U19.33
I2C_SDA5: J26.3, J29.1, R92.1, U23.33
I2C_SDA6: J31.3, J34.1, R110.1, U27.33
I2C_SDA7: J36.3, J39.1, R128.1, U31.33
I2C_SDA8: J41.3, J44.1, R146.1, U35.33
I2C_SDA9: J46.3, J49.1, R164.1, U39.33
I2C_SDA10: J51.3, J54.1, R182.1, U43.33
I2C_SDA11: J56.3, J59.1, R200.1, U47.33
unnamed: D4.C, R3.2
unnamed: I2C_PU.3, R10.2
unnamed: I2C_PU.1, R17.2
unnamed: D3.A, LED.1
unnamed: D5.1, J5.A6, J5.B6
unnamed: D5.3, J5.A7, J5.B7
unnamed: D3.C, R8.2
unnamed: C2.1, C3.1, DA_MEAS.1, U1.15, U1.34, U1.35
unnamed: D1.C, U3.1
unnamed: CHG.3, R6.2
unnamed: J5.A5, R1.1
unnamed: J5.B5, R4.1
unnamed: D5.6, R11.1
unnamed: CHG.2, U3.5
unnamed: C8.1, D2.C, MEAS.1, MEAS.3, Q1.2, R16.2
unnamed: D5.4, R12.1
unnamed: D1.A, R2.1
unnamed: R11.2, U2.1
unnamed: R12.2, U2.2
unnamed: CHG.1, R14.2
unnamed: Q1.1, R18.2
unnamed: MEAS.2, MEAS.4, U7.1
unnamed: CHG_LED.1, R2.2
unnamed: J5.SHLD1, J5.SHLD2, J5.SHLD3, J5.SHLD4, J5.SHLD5, J5.SHLD6, J5.SHLD7, J5.SHLD8, SHLD.2
unnamed: D7.C, U5.1
unnamed: CH_PWR.1, U2.7, U2.10
unnamed: CHG1.2, U5.5
unnamed: D7.A, R25.1
unnamed: D8.C, R26.2
unnamed: I2C_PU1.3, R9.2
unnamed: I2C_PU1.1, R19.2
unnamed: J8.A5, R21.1
unnamed: J8.B5, R22.1
unnamed: C4.1, D6.C, MEAS1.1, MEAS1.3, Q2.2, R24.2
unnamed: D9.C, R28.2
unnamed: D9.A, LED1.1
unnamed: D10.1, J8.A6, J8.B6
unnamed: D10.3, J8.A7, J8.B7
unnamed: D10.6, R31.1
unnamed: D10.4, R32.1
unnamed: R31.2, U8.1
unnamed: R32.2, U8.2
unnamed: CHG1.3, R27.2
unnamed: CHG1.1, R34.2
unnamed: Q2.1, R35.2
unnamed: J8.SHLD1, J8.SHLD2, J8.SHLD3, J8.SHLD4, J8.SHLD5, J8.SHLD6, J8.SHLD7, J8.SHLD8, SHLD1.2
unnamed: MEAS1.2, MEAS1.4, U4.1
unnamed: CHG_LED1.1, R25.2
unnamed: CH_PWR1.1, U8.7, U8.10
unnamed: C13.1, C14.1, DA_MEAS1.1, U6.15, U6.34, U6.35
unnamed: D12.C, U10.1
unnamed: CHG2.2, U10.5
unnamed: D12.A, R43.1
unnamed: D13.C, R44.2
unnamed: I2C_PU2.3, R37.2
unnamed: I2C_PU2.1, R38.2
unnamed: J13.A5, R39.1
unnamed: J13.B5, R40.1
unnamed: C15.1, D11.C, MEAS2.1, MEAS2.3, Q3.2, R42.2
unnamed: D14.C, R46.2
unnamed: D14.A, LED2.1
unnamed: D15.1, J13.A6, J13.B6
unnamed: D15.3, J13.A7, J13.B7
unnamed: D15.6, R49.1
unnamed: D15.4, R50.1
unnamed: R49.2, U12.1
unnamed: R50.2, U12.2
unnamed: CHG2.3, R45.2
unnamed: CHG2.1, R52.2
unnamed: Q3.1, R53.2
unnamed: J13.SHLD1, J13.SHLD2, J13.SHLD3, J13.SHLD4, J13.SHLD5, J13.SHLD6, J13.SHLD7, J13.SHLD8, SHLD2.2
unnamed: MEAS2.2, MEAS2.4, U9.1
unnamed: CHG_LED2.1, R43.2
unnamed: CH_PWR2.1, U12.7, U12.10
unnamed: C20.1, C21.1, DA_MEAS2.1, U11.15, U11.34, U11.35
unnamed: D17.C, U14.1
unnamed: CHG3.2, U14.5
unnamed: D17.A, R61.1
unnamed: D18.C, R62.2
unnamed: I2C_PU3.3, R55.2
unnamed: I2C_PU3.1, R56.2
unnamed: J18.A5, R57.1
unnamed: J18.B5, R58.1
unnamed: C22.1, D16.C, MEAS3.1, MEAS3.3, Q4.2, R60.2
unnamed: D19.C, R64.2
unnamed: D19.A, LED3.1
unnamed: D20.1, J18.A6, J18.B6
unnamed: D20.3, J18.A7, J18.B7
unnamed: D20.6, R67.1
unnamed: D20.4, R68.1
unnamed: R67.2, U16.1
unnamed: R68.2, U16.2
unnamed: CHG3.3, R63.2
unnamed: CHG3.1, R70.2
unnamed: Q4.1, R71.2
unnamed: J18.SHLD1, J18.SHLD2, J18.SHLD3, J18.SHLD4, J18.SHLD5, J18.SHLD6, J18.SHLD7, J18.SHLD8, SHLD3.2
unnamed: MEAS3.2, MEAS3.4, U13.1
unnamed: CHG_LED3.1, R61.2
unnamed: CH_PWR3.1, U16.7, U16.10
unnamed: C27.1, C28.1, DA_MEAS3.1, U15.15, U15.34, U15.35
unnamed: D22.C, U18.1
unnamed: CHG4.2, U18.5
unnamed: D22.A, R79.1
unnamed: D23.C, R80.2
unnamed: I2C_PU4.3, R73.2
unnamed: I2C_PU4.1, R74.2
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

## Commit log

2022-03-15 First hardware commit
    * Added datasheet and DA16200 eagle library
    * Starting from the RP2040 thing plus design files
    [DA16200_Thing_Plus.brd, DA16200_Thing_Plus.sch]
2022-03-29 Working on initial design
    * Schematic almost done
    * Laying-out parts
    [DA16200_Thing_Plus.brd, DA16200_Thing_Plus.sch]
2022-03-29 Working on schematic
    [DA16200_Thing_Plus.brd, DA16200_Thing_Plus.sch]
2022-03-29 Pete's schematic suggestions
    * Add jumper to disable PWR LED
    * TVS protection for D+/D- lines
    * Add low value resistor (200) on reset line
    * multiple charge current options
    * Add 100 ohm between gate of Q2 and V_USB
    [DA16200_Thing_Plus.brd, DA16200_Thing_Plus.sch]
2022-03-29 Switch pins around
    [DA16200_Thing_Plus.brd, DA16200_Thing_Plus.sch]
2022-03-31 Eric's suggestions
    * Add external flash
    * Add a jumper to measure current draw
    [DA16200_Thing_Plus.brd, DA16200_Thing_Plus.sch]
2022-03-31 Add documentation
    [DA16200_Thing_Plus.brd]
2022-04-04 More buzzard
    [DA16200_Thing_Plus.brd]
2022-04-05 Design review
    [DA16200_Thing_Plus.brd, DA16200_Thing_Plus.sch]
2022-04-05 Design review updates
    Schematic:
    * Re-wire wakeup pins to match app schematic and previous designs
    * Change SHLD jumper to NC
    * Remove "ANT_GND" pin label from DA16200 symbol
    Board:
    * Draw polygon to connect shield pins of USBC connector on top and bottom
    * Rename button GPIOC7
    * Breakout JTAG pins to TPs on the bottom
    * Redraw polygons for middle layers to avoid the antenna GND keepout
    * Fixed LED label on the jumper and the pin
    * Changed "CURR" label to "MEAS"
    [DA16200_Thing_Plus.brd, DA16200_Thing_Plus.sch]
2022-04-05 QC Double-check updates
    * CURR jumper to MEAS
    * Move TPs onto 0.1 grid
    * line up LEDs
    [DA16200_Thing_Plus.brd, DA16200_Thing_Plus.sch]
2022-04-12 Approve overlap errors on DRC
    [DA16200_Thing_Plus.brd]
2022-04-12 Add GND vias to board
    [DA16200_Thing_Plus.brd]
2022-04-12 Generate gerbers for proto (single board)
    [DA16200_Thing_Plus.GBL, DA16200_Thing_Plus.GBO, DA16200_Thing_Plus.GBP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]
2022-04-12 Updated a few parts
    [DA16200_Thing_Plus.brd, DA16200_Thing_Plus.sch]
2022-04-19 Fix some names on schematic
    [DA16200_Thing_Plus.brd, DA16200_Thing_Plus.sch]
2022-04-29 Add EVK schematics to repo for reference
    [DA16200S1_IF_09_210205.sch, DA16200_IF_09_200204_BOM.xlsx]
2022-05-09 Move LiPo, JTAG connector, and MEAS jumper to make room for connectors.
    [DA16200_Thing_Plus.brd]
2022-05-10 Add "DNP" to external QSPI flash circuitry
    [DA16200_Thing_Plus.brd, DA16200_Thing_Plus.sch]
2022-05-17 Updates for Red's
    * Added a NC jumper on the RTC_PWR_KEY pin to default to 3.3V. Users can cut the jumper to enter into sleep mode 1
    [DA16200_Thing_Plus.brd, DA16200_Thing_Plus.sch]
2022-05-20 Remove external flash!
    The "F" pins are the pins internally connecting the DA16200 with the in-module 4MB SFLASH!
    [DA16200_Thing_Plus.brd, DA16200_Thing_Plus.sch]
2022-05-20 Add SPDT switch for RTC_PWR_KEY
    Added surface mount switch to pull RTC_PWR_KEY to 3.3V or GND
    * Needed to extend the length of board by one grid space
    [DA16200_Thing_Plus.brd, DA16200_Thing_Plus.sch]
2022-05-20 Add uSD friction fit to schematic
    * Renamed net labels to match connecting to the uSD socket defined by UM-WI-046 pg 30
    [DA16200_Thing_Plus.brd, DA16200_Thing_Plus.sch]
2022-05-25 Add charge LED jumper
    Add charge LED jumper
    [DA16200_Thing_Plus.brd, DA16200_Thing_Plus.sch]
2022-05-27 Update AP2112K to XC6222B33
    [DA16200_Thing_Plus.brd, DA16200_Thing_Plus.sch]
2022-05-27 Update measures
    [DA16200_Thing_Plus.brd]
2022-05-27 Add jumper to remove 3.3V from CH340E
    [DA16200_Thing_Plus.brd, DA16200_Thing_Plus.sch]
2022-05-31 Change "IOC7" label to "IOA7" text
    [DA16200_Thing_Plus.brd]
2022-06-03 Remove SD card socket from design
    [DA16200_Thing_Plus.brd, DA16200_Thing_Plus.sch]
2022-06-06 Approve DRC errors and remove wire stub
    [DA16200_Thing_Plus.brd]
2022-06-07 Design review updates
    * Remove "Ohm" from R11/R12 value
    * Add schematic symbol for ground onto USB SHLD
    * set layers in order
    * Fix polygons to line up in DA16200 keep out area
    * Add vias to stitch GND
    * Fix some acid traps
    * Evenly space out some traces
    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
    [DA16200_Thing_Plus.brd, DA16200_Thing_Plus.sch]
2022-06-08 Design review updates
    Change DRC to 4 layer minimum rules, lots of little updates to avoid overlap. Annular ring size increased
    [DA16200_Thing_Plus.brd, DA16200_Thing_Plus.sch]
2022-06-08 Fixing buzzard labels
    [DA16200_Thing_Plus.brd]
2022-06-09 finish adding buzzard labels
    [DA16200_Thing_Plus.brd]
2022-06-09 Design review updates
    * MEAS trace flipped to the bottom
    * Move components from bottom of board to the top
    [DA16200_Thing_Plus.brd]
2022-06-09 Run through engineering checklist
    [DA16200_Thing_Plus.brd, DA16200_Thing_Plus.sch]
2022-06-09 Update back buzzard labels
    Pin labels should be rounded and call out GPIO it's connected to
    [DA16200_Thing_Plus.brd]
2022-06-09 Remove extra gerbers
    [DA16200_Thing_Plus.GBL, DA16200_Thing_Plus.GBO, DA16200_Thing_Plus.GBP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]
2022-06-10 Some buzzard updates
    * Remove confusing labeling
    * Switch 3V3 and GND labels on SPDT switch because they were backwards
    [DA16200_Thing_Plus.brd]
2022-06-10 Final panel
    Kasey generated and approved!
    [DA16200_Thing_Plus-Panel.brd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]
2022-07-28 Fix funky behaviors
    Add 0.1uF filter cap to DA16200
    Add 10k pullup to reset line
    [DA16200_Thing_Plus.brd, DA16200_Thing_Plus.sch]
2022-07-28 Bump version number to v11
    [DA16200_Thing_Plus.brd, DA16200_Thing_Plus.sch]
2022-07-28 Update production files
    [DA16200_Thing_Plus-Panel.brd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]
2022-07-28 Design review updates
    Add extra 0.1uF cap near VDD_DIO2
    Add NC jumper near SCLK pad to optionally remove pullup resistor and reset button
    [DA16200_Thing_Plus.brd, DA16200_Thing_Plus.sch]
2022-09-13 Add dimensions
    Add board dimensions
    [DA16200_Thing_Plus.brd]
2022-09-13 Renamed file
    add schematic to be more descriptive
2022-09-13 Updated files
    Includes revisions
    - pull-up resistor
    - added filter caps
    - reset jumper
    Added board dimensions
2022-09-14 rename and move board files

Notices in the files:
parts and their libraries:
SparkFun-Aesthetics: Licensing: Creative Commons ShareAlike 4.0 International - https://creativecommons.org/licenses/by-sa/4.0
